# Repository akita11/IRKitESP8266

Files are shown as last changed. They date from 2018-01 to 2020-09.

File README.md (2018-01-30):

IRKitESP8266
=====

IRKit Clone on ESP8266

## これは何

Toshiyuki Kawashima氏の[ESP8266IRKit](https://github.com/toskaw/ESP8266IRKit) をベースに、以下の2点の追加・改変を行ったものです。
* ボタンを追加、長押しで初期化(電源ON時にも有効)
* 動作状態をLED(WS2812B)で表示

## 基板データ

IRKitESP8266.{brd,sch}がEagleデータです。適当な方法で製造してください。

※LED電流制限抵抗としてR4とR11の2つがありますが、どちらか一方のみの実装でよいです。流れる電流からして、R11のほうがオススメです（13Ωと書いてありますが、10Ω前後のものでよいはず）。ただこのあたりは要調整で、SwitchScienceのESP-IRではもっと小さな抵抗を使っているようです。10Ωか4.7Ωの0603サイズ（インチ：ミリだと1608）を、R4とR11の両方に実装するくらいでいいかもです（試していないのでLED破損の恐れがありますので要注意）。

なおオリジナルIRKitの基板と、穴の位置やコネクタの位置を基本的にあわせてあるので、オリジナルの筐体を流用できます。ただしオリジナルの赤外線LEDは2個なので、その筐体に合わせる場合は、LEDはD3とD4のみとりつけ、電流制限抵抗R4/R11もそれにあわせて調節してください。なおステータス表示LEDは基板上に上向きに実装されるため、オリジナル筐体にはあいません。またタクトスイッチの位置・種類がオリジナルと異なります。ご了承ください。

※初期化用タクトスイッチをオリジナル筐体にあうように追加し、プログラム用ショートピンの位置を少しずらし、ESP8266のアンテナ周囲のベタGNDを設計ガイドラインにあわせてあけたv1.1を追加しました(C5の位置が変更になっています)。ただし実際の製造・検証はしてませんのでご了承ください。

## ソースコード

上記のToshiyuki Kawashima氏の「作り方（ソースからコンパイルする方法）」の通りに進めます。

## 使い方

基本的に純正IRKitと同じです。スマホのIRKitアプリで初期設定を行ってください。初期パスワードは"0000000000"です。

## 参考にしたもの

* [minlRum](https://github.com/9SQ/minIRum)

* [IRKit](http://getirkit.com/)

* [ESP8266IRKit](https://github.com/toskaw/ESP8266IRKit)

## 直近のToDo
* LED点滅を、一応実装した（1秒周期）が、IR受信時の点滅を本家にあわせたい。
* 基板の外形・部品位置を、オリジナル筐体にあうように、以下の修正をしたい。
** uUSBコネクタの位置
** 初期化タクトスイッチ
** 角を丸める

## Author

Junichi Akita (@akita11, akita@ifdl.jp)

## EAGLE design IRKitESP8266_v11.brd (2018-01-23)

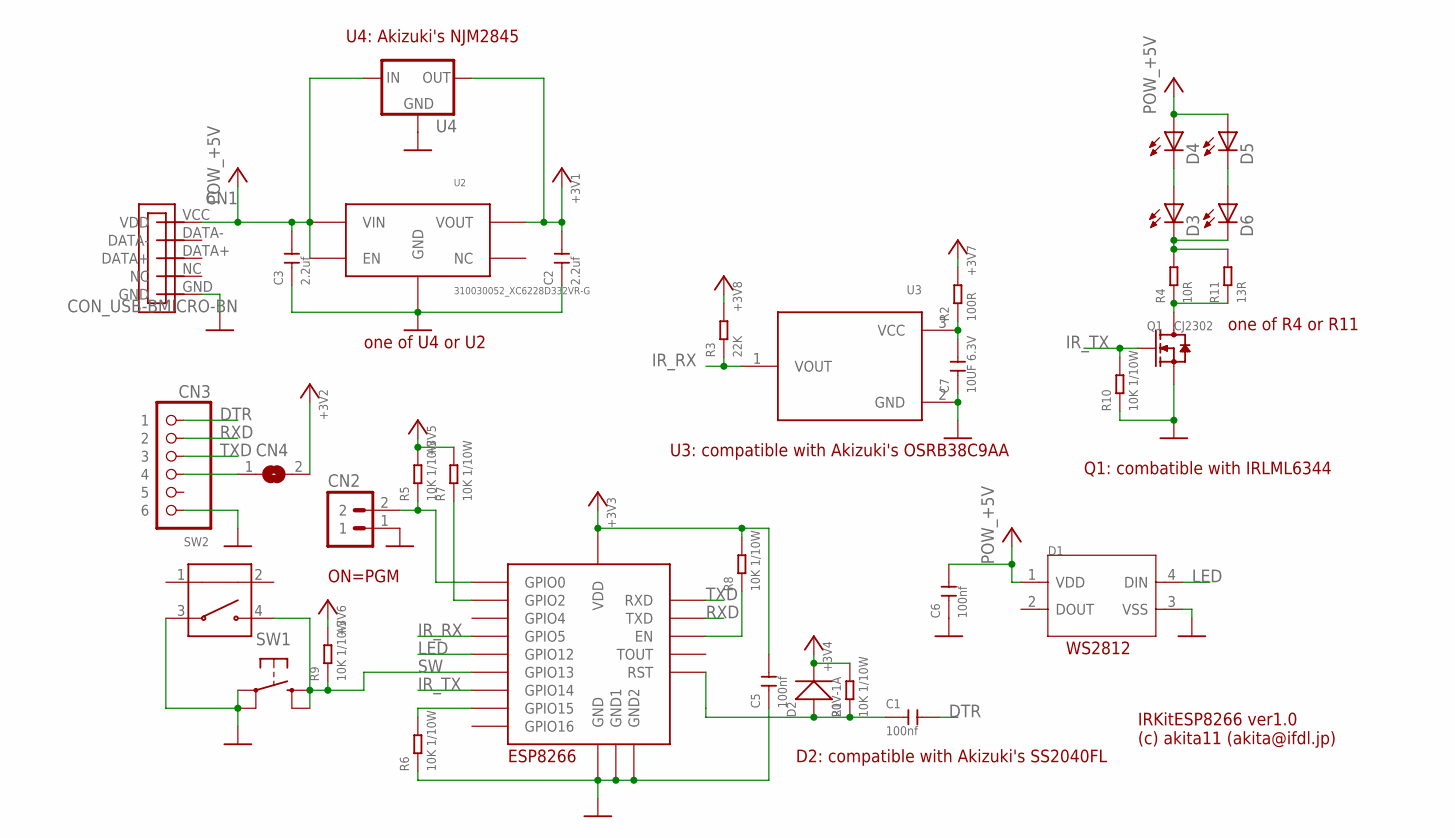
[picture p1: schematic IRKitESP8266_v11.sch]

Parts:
C1, C5, C6: 100nf; C0603
C2, C3: 2.2uf; C0603
C7: 10UF 6.3V; C0603
CN1: CON_USB-BMICRO-BN; MICRO-USB_B_NARROW
CN2: CON_PINHD-1X2PTH; SPARKFUN_1X02
CN3: CON_PINHD-1X6; 1X06
CN4: JUMPER_SJ
D1: SMD-RGB-LED-4P'WS2812B'; LED4-SMD-5050
D2: 20V-1A; SOD-123
D3, D4, D5, D6: LED5MM; SPARKFUN_LED5MM
Q1: CJ2302; SOT-23
R1, R5, R6, R7, R8, R9, R10: 10K 1/10W; R0603
R2: 100R; R0603
R3: 22K; R0603
R4: 10R; R0603
R11: 13R; R1206
SW1: SW_TACTTH; SW_B3F-10XX
SW2: TS-1188E
U1: MOD_ESP8266WROOM02
U2: 310030052_XC6228D332VR-G; SOT25J
U3: TSOP382
U4: REG_78XXTO252-3; TO-252-3

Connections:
+3V3: C2.2, C5.2, CN4.2, D2.-, R1.2, R2.2, R3.2, R5.2, R7.2, R8.2, R9.2, U1.P$1 (VDD), U2.P$5 (VOUT), U4.P$3 (OUT)
+5V: C3.2, C6.2, CN1.VCC (VDD), D1.1 (VDD), D4.A, D5.A, U2.P$1 (VIN), U2.P$3 (EN), U4.P$1 (IN)
DTR: C1.2, CN3.1
GND: C2.1, C3.1, C5.1, C6.1, C7.1, CN1.GND, CN2.1, CN3.6, D1.3 (VSS), Q1.2 (S), R6.1, R10.1, SW1.3, SW1.4 (P1), SW2.3, U1.P$9 (GND), U1.P$13 (GND1), U1.P$18 (GND2), U2.P$2 (GND), U3.2 (GND), U4.P$2 (GND)
IR_RX: R3.1, U1.P$14 (GPIO5), U3.1 (VOUT)
IR_TX: Q1.1 (G), R10.2, U1.P$3 (GPIO14)
LED: D1.4 (DIN), U1.P$4 (GPIO12)
unnamed: C1.1, D2.+, R1.1, U1.P$15 (RST)
unnamed: R6.2, U1.P$6 (GPIO15)
unnamed: CN2.2, R5.1, U1.P$8 (GPIO0)
unnamed: R7.1, U1.P$7 (GPIO2)
unnamed: CN3.4, CN4.1
unnamed: R8.1, U1.P$2 (EN)
unnamed: C7.2, R2.1, U3.3 (VCC)
unnamed: Q1.3 (D), R4.1, R11.1
unnamed: D3.K (C), D6.K (C), R4.2, R11.2
unnamed: D3.A, D4.K (C)
unnamed: D5.K (C), D6.A
RXD: CN3.2, U1.P$12 (TXD)
SW: R9.1, SW1.1 (S), SW1.2 (S1), SW2.4, U1.P$5 (GPIO13)
TXD: CN3.3, U1.P$11 (RXD)

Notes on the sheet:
U3: compatible with Akizuki's OSRB38C9AA
D2: compatible with Akizuki's SS2040FL
ON=PGM
WS2812
ESP8266
Q1: combatible with IRLML6344
IRKitESP8266 ver1.0 (c) akita11 (akita@ifdl.jp)
U4: Akizuki's NJM2845
one of U4 or U2
one of R4 or R11

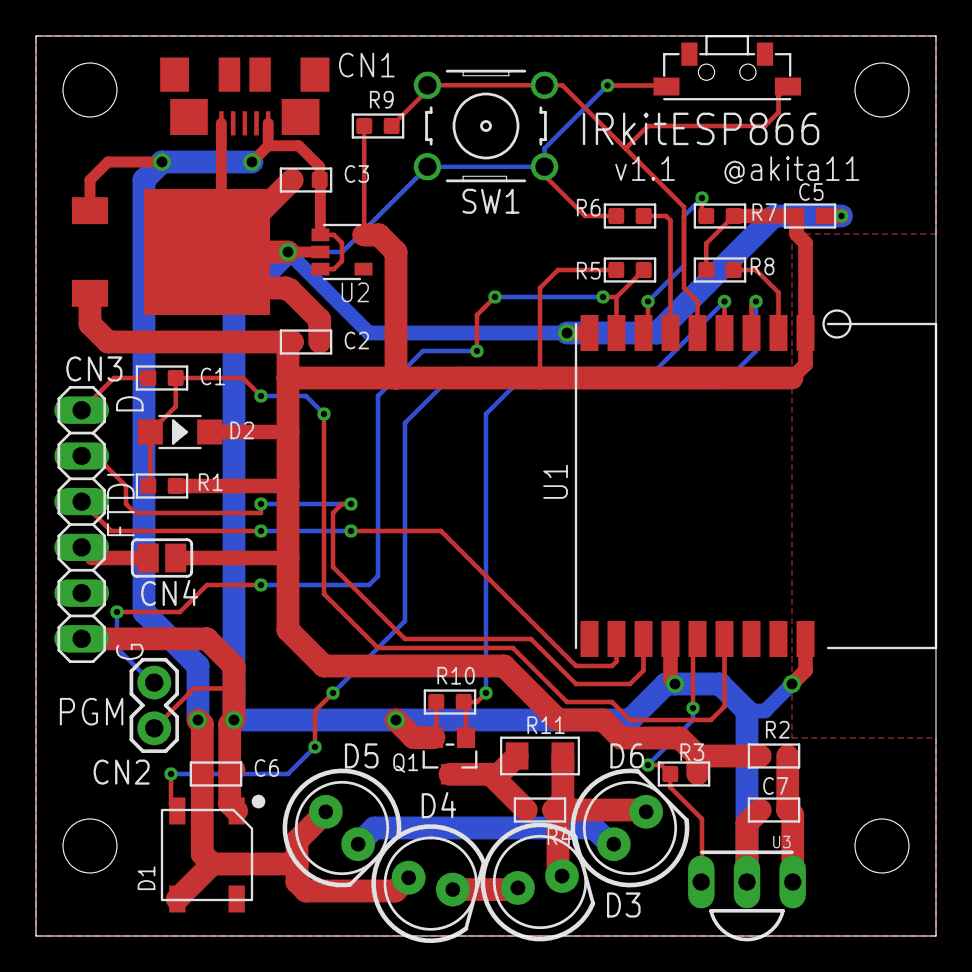
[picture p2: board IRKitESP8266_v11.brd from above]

Board: 2 copper layers, 50.0 x 50.0 mm, 34 parts (0 on the bottom side), 21 nets.

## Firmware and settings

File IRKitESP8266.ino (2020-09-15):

/*
 Copyright (C) 2018 Junichi Akita (@akita11, akita@ifdl.jp)

 This program is based on Toshiyuki Kawashima's ESP8266IRKit
 https://github.com/toskaw/ESP8266IRKit

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
 You should have received a copy of the GNU General Public License
 along with this program.  If not, see <http://www.gnu.org/licenses/>.
*/

/*
 Copyright (C) 2017 Toshiyuki Kawashima
  
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
 You should have received a copy of the GNU General Public License
 along with this program.  If not, see <http://www.gnu.org/licenses/>.
*/
#include "AsyncClient.h"
#include "IrPacker.h"
#include <EEPROM.h>

#include <IRrecv.h>
#include <IRremoteESP8266.h>
#include <IRsend.h>
#include <IRtimer.h>
#include <IRutils.h>
#include <ir_Argo.h>
#include <ir_Daikin.h>
#include <ir_Fujitsu.h>
#include <ir_Kelvinator.h>
#include <ir_LG.h>
#include <ir_Mitsubishi.h>
#include <ir_Trotec.h>
#include <Adafruit_NeoPixel.h> // for IRkitESP8266 by akita11

#include <ESP8266WiFi.h>
#include <ESP8266WebServer.h>
#include <ESP8266mDNS.h>
#include <aJSON.h>
#include <base64.h>

#include <Ticker.h>

#define VERSION "3.2.0.3.esp8266"
#define HOST "http://deviceapi.getirkit.com"
#define RECV_TIMEOUT 100U
#define RECV_BUFF 1024
#define JSON_BUFF 4096
#define SHARED_BUFFER_SIZE 512

const int send_pin = 14;
const int recv_pin = 5;
const int led_pin = 12; // for IRkitESP8266 by akita11
const int sw_pin = 13;  // for IRkitESP8266 by akita11
const char WAIT_RESPONSE = 'a';
const char DONE = 'b';
static uint32_t newest_message_id = 0;
char localName[10] = "IRKit";
uint16 irLen = 0;

// for IRkitESP8266 by akita11
Adafruit_NeoPixel pix = Adafruit_NeoPixel(1, led_pin, NEO_GRB + NEO_KHZ800);
Ticker ticker;
uint8_t LEDr = 0, LEDg = 0, LEDb = 0, fBlink = 0;
#define BLINK_INTERVAL 500 // [ms], 1000->500

// for IRkitESP8266 by akita11
// IRKit LED
//  赤       Wi-Fiに接続していない
//  赤点滅   セットアップ待ち
//  緑点滅   Wi-Fiに接続中
//  水色点滅 Wi-Fi接続成功！HTTPサーバなどセットアップ中
//  青	     正常
//  青点滅   赤外線信号を送受信中
//  ※現在は、青点滅は受信に同期せず、他と同じ一定周期点滅にしている(akita11)

void set_led(int r, int g, int b, uint8_t f_blink){
  LEDr = r; LEDg = g; LEDb = b;
  fBlink = f_blink;
  pix.setPixelColor(0, pix.Color(LEDr, LEDg, LEDb));
  pix.show();
}

void LEDblink()
{
  if (fBlink != 0){
    if (fBlink == 1){
      pix.setPixelColor(0, pix.Color(LEDr, LEDg, LEDb));
      fBlink = 2;
    }
    else if (fBlink == 2){
      pix.setPixelColor(0, pix.Color(0, 0, 0));
      fBlink = 1;
    }
    pix.show();
  }
}

const int LED_FULL = 50; // 100 -> 50

int polling = 0;
struct CONFIG {
  char init;
  char ssid[32];
  char pass[64];
  char devicekey[32];
};

CONFIG gSetting;

void factory_reset()
{
  Serial.println("factory initialize; erasing WiFi settings");
  int i;
  for (i =0; i < 5; i++){
    set_led(LED_FULL, LED_FULL, LED_FULL, 0); delay(500);
    set_led(0, 0, 0, 0); delay(500);
  }
  gSetting.init = 0;
  strcpy(gSetting.ssid, "");
  strcpy(gSetting.pass, "");
  EEPROM.put<CONFIG>(0, gSetting);
  EEPROM.commit();
  EEPROM.end();
  ESP.reset();
}
int sw_press_time = 0;  // for IRkitESP8266 by akita11
const int sw_long_press_time = 500;  // [x10ms] for IRkitESP8266 by akita11

struct irpacker_t packer_state;
ESP8266WebServer webServer(80);
AsyncClient polling_client;
char sharedbuffer[ SHARED_BUFFER_SIZE ];

IRsend irsend(send_pin);
IRrecv irrecv(recv_pin, RECV_BUFF, RECV_TIMEOUT, true);

#define ERR_NOBODY -1
#define ERR_FORMAT -2
#define ERR_EMPTY -3
char json[JSON_BUFF];

int irsendMessage(String& req) {
  int ret = 0;
  if (req.length() == 0) return ERR_EMPTY;
  irrecv.disableIRIn();
  
  req.toCharArray(json, JSON_BUFF);
  Serial.println(json);
  aJsonObject* root = aJson.parse(json);
  if (root != NULL) {
    aJsonObject* freq = aJson.getObjectItem(root, "freq");
    aJsonObject* data = aJson.getObjectItem(root, "data");
    aJsonObject* id = aJson.getObjectItem(root, "id");
    if (freq != NULL && data != NULL) {
      aJsonObject* node = data->child;
      if (node != NULL) {
        uint16_t d_size = 0;
        while (node) {
          d_size += 1;
          node = node->next;       
        }
        uint16_t rawData[d_size];
        int i = 0;
        node = data->child;
        while (node)  {
          rawData[i] = node->valueint;
          i += 1;
          node = node->next;
        }
        if (freq->type == aJson_Int) {
          irsend.sendRaw(rawData, d_size, (uint16_t)freq->valueint);
        }
        else if (freq->type == aJson_Float) {
          irsend.sendRaw(rawData, d_size, (uint16_t)freq->valuefloat);          
        }
        else {
          // 本当はエラーだけど38決め打ち
          irsend.sendRaw(rawData, d_size, 38);
        }
        Serial.println("irsend");
        if (id == NULL) {
          // polling suspend
          polling = 1;
        }
      }
      else {
        ret = ERR_FORMAT;
      }
      
      if (id != NULL) {
        newest_message_id = id->valueint;
       }
    } else {
      ret =  ERR_FORMAT;
    }
    aJson.deleteItem(root);
  } else {
    ret = ERR_NOBODY;
  }
  irrecv.enableIRIn();
  return ret;  
}

void sendheader() {
  webServer.sendHeader("Access-Control-Allow-Origin", "*");
  String server = "IRKit/";
  server += VERSION;
  webServer.sendHeader("Server", server);
}

void handleMessages() {
  Serial.println(webServer.uri().c_str());
  sendheader();
  if (!webServer.hasHeader("X-Requested-With")) {
    webServer.send(400, "text/plain", "Invalid Request");
    return;
  }
  if (webServer.method() == HTTP_POST) {
    Serial.println("post");
    String req = webServer.arg(0);
    if (req != NULL) {
      int err = irsendMessage(req);
      if (err == 0) {
        webServer.send(200, "text/plain", "ok");
      }
      else if (err == ERR_FORMAT) {
        webServer.send(400, "text/plain", "Invalid JSON format");
      }
      else {
        webServer.send(400, "text/plain", "No Data");
      }
    }
    else {
      Serial.println("err");
      webServer.send(400, "text/plain", "No Data");      
    }
  }
  else if (webServer.method() == HTTP_GET) {
    String s = "{\"format\":\"raw\",\"freq\":38,\"data\":[";
    int length = irLen;
    irpacker_unpack_start(&packer_state);
    for (int i= 0; i < length - 1; i += 1) {
      s += irpacker_unpack(&packer_state);
      s += ",";
    }
    s += irpacker_unpack(&packer_state);
    s += "]}";
    webServer.send(200, "text/plain", s);
  }
}

void handleKeys() {
  // devicekey=[0-9A-F]{32}
  if (!webServer.hasHeader("X-Requested-With")) {
    webServer.send(400, "text/plain", "Invalid Request");
    return;
  }
  char body[64];
  char url[64];
  sprintf(body, "devicekey=%s", gSetting.devicekey);
  HTTPClient client;
  sprintf(url, "%s%s", HOST, "/k");
  client.begin(url);
  client.setUserAgent("IRKit");
  client.addHeader("Content-Type", "application/x-www-form-urlencoded");
  int code = client.POST((uint8_t*)body, strlen(body));
  if (code == HTTP_CODE_OK) {
    sendheader();
    webServer.send(200, "text/plain", client.getString()); 
  }
  client.end();
}
void handleIndex() {
  String s = "<html lang=\"en\"><head><meta charset=\"utf-8\"/><meta name=\"viewport\" content=\"width=device-width, initial-scale=1\"><title>minIRum</title><link rel=\"stylesheet\" href=\"https://cdnjs.cloudflare.com/ajax/libs/twitter-bootstrap/3.3.7/css/bootstrap.min.css\" /><script src=\"https://cdnjs.cloudflare.com/ajax/libs/jquery/3.2.1/jquery.min.js\"></script><script src=\"https://cdnjs.cloudflare.com/ajax/libs/twitter-bootstrap/3.3.7/js/bootstrap.min.js\"></script></head><body><div class=\"container\"><div class=\"row\"><div class=\"col-md-12\"><h1>minIRum console <small>";
  s += localName;
  s += ".local</small></h1><p>IP address: ";
  s += String(WiFi.localIP()[0]) + "." + String(WiFi.localIP()[1]) + "." + String(WiFi.localIP()[2]) + "." + String(WiFi.localIP()[3]);
  s += "</p><hr><div class=\"form-group\"><textarea class=\"form-control\" id=\"message\" rows=\"10\"></textarea></div><button class=\"btn btn-primary\" id=\"get\">GET</button> <button class=\"btn btn-success\" id=\"post\">POST</button> <button class=\"btn btn-info\" id=\"ifttt\">IFTTT PARAM</button></div>";
  s += "<script>var xhr = new XMLHttpRequest();var textarea = document.getElementById(\"message\");document.getElementById(\"get\").addEventListener(\"click\", function () {xhr.open('GET', '/messages', true);xhr.setRequestHeader('X-Requested-With', 'curl');xhr.onreadystatechange = function() {if(xhr.readyState == 4) {textarea.value =xhr.responseText;}};xhr.send(null);});";
  s += "document.getElementById(\"post\").addEventListener(\"click\", function () {data = textarea.value;xhr.open('POST', '/messages', true);xhr.onreadystatechange = function() {if(xhr.readyState == 4) {alert(xhr.responseText);}};xhr.setRequestHeader('Content-Type', 'application/json');xhr.setRequestHeader('X-Requested-With', 'curl');xhr.send(data);});";
  s += "document.getElementById(\"ifttt\").addEventListener(\"click\", function () {xhr.open('POST', '/keys', true);xhr.onreadystatechange = function() {if(xhr.readyState == 4) {data = JSON.parse(xhr.responseText);param = 'clienttoken=' + data.clienttoken; var xhr2 = new XMLHttpRequest(); xhr2.open('POST', 'https://api.getirkit.com/1/keys', true);xhr2.onreadystatechange = function() {if(xhr2.readyState == 4) {data=JSON.parse(xhr2.responseText);message = textarea.value;param = 'clientkey=' + data.clientkey + '&deviceid=' + data.deviceid +'&message=' + message; textarea.value = param;}};xhr2.setRequestHeader('Content-Type', 'application/x-www-form-urlencoded');xhr2.send(param);}};xhr.setRequestHeader('Content-Type', 'application/json');xhr.setRequestHeader('X-Requested-With', 'curl');xhr.send('');});";
  s += "</script></body></html>";
  sendheader();
  webServer.send(200, "text/html", s);
}

void handleNotFound() {
  Serial.println(webServer.uri().c_str());
  Serial.println("404");
  sendheader();
  webServer.send(404, "text/plain", "Not found.");
}

void handleReset() {
  sendheader();
  if (!webServer.hasHeader("X-Requested-With")) {
    webServer.send(400, "text/plain", "Invalid Request");
    return;
  }
  webServer.send(200, "text/plain", "Reboot.");
  webServer.close();
  gSetting.init = 0;
  Serial.println("reset");
  EEPROM.put<CONFIG>(0, gSetting);
  EEPROM.commit();
  EEPROM.end();

  // reset
  ESP.reset();
}

void decodeParam(String& param, char *buffer) {
  int length = param.length();
  char high = 0;
  char low = 0;
  for (int i = 0; length > i; i+=2) {
      high = param.charAt(i);
      if (high < 'A') {
        high = high - '0';
      }
      else {
        high = high - 'A' + 10;
      }
      high *= 16;
      low = param.charAt(i + 1);
      if (low < 'A') {
        low = low - '0';
      }
      else {
        low = low - 'A' + 10;
      }
      *buffer = (char)(high + low);
      buffer += 1;
  }
  *buffer = '\0';
}

void handleWifiPost() {
  if (!webServer.hasHeader("X-Requested-With")) {
    webServer.send(400, "text/plain", "Invalid Request");
    return;
  }

  String data = webServer.arg(0);
  Serial.println("wifi request");
  Serial.println(data.c_str());

  // decode ssid
  int index = data.indexOf('/');
  int end_index = data.indexOf('/', index + 1);
  String param = data.substring(index + 1, end_index);
  Serial.println(param.c_str());
  decodeParam(param, gSetting.ssid);
  Serial.println(gSetting.ssid);

  // decode password
  index = data.indexOf('/', end_index);
  end_index = data.indexOf('/', index + 1);
  param = data.substring(index + 1, end_index);
  Serial.println(param.c_str());
  decodeParam(param, gSetting.pass);
  Serial.println(gSetting.pass);

  // decode devicekey
  index = data.indexOf('/', end_index);
  end_index = data.indexOf('/', index + 1);
  param = data.substring(index + 1, end_index);
  strcpy(gSetting.devicekey, param.c_str());
  Serial.println(gSetting.devicekey);
  
  gSetting.init = WAIT_RESPONSE;
  EEPROM.put<CONFIG>(0, gSetting);
  EEPROM.commit();
  EEPROM.end();
  String html = "";
  html += "<h1>WiFi Settings</h1>";
  webServer.send(200, "text/html", html);
  webServer.close();
  // reset
  ESP.reset();
}

String dumpIRcode(decode_results *results) {
  String s = "";
  for (int i = 1;  i < results->rawlen;  i++) {
    s += results->rawbuf[i] * RAWTICK;
    if ( i < results->rawlen - 1 ) s += ",";
  }
  return s;
}

void APMode() {
    char* ssid;
    const char* password = "0000000000";

    ssid = localName;
    IPAddress local_IP(192,168,1,1);
    IPAddress subnet(255,255,255,0);
    WiFi.mode(WIFI_AP);
    WiFi.softAPConfig(local_IP, local_IP, subnet);
    WiFi.softAP(ssid, password);
    delay(1000);
    Serial.println("");
    Serial.println("softAP Start");  
    Serial.print("IP address: ");
    Serial.println(WiFi.softAPIP());
#if 0    
    if (MDNS.begin(localName, WiFi.softAPIP())) {
      MDNS.addService("irkit", "tcp", 80);
      Serial.println("MDNS responder started.");
      Serial.print("http://");
      Serial.print(localName);
      Serial.println(".local");
    }
#endif
    webServer.on("/wifi", HTTP_POST, handleWifiPost);
}

#if 0
void dump(decode_results *results) {
  // Dumps out the decode_results structure.
  // Call this after IRrecv::decode()
  uint16_t count = results->rawlen;
  if (results->decode_type == UNKNOWN) {
    Serial.print("Unknown encoding: ");
  } else if (results->decode_type == NEC) {
    Serial.print("Decoded NEC: ");
  } else if (results->decode_type == SONY) {
    Serial.print("Decoded SONY: ");
  } else if (results->decode_type == RC5) {
    Serial.print("Decoded RC5: ");
  } else if (results->decode_type == RC5X) {
    Serial.print("Decoded RC5X: ");
  } else if (results->decode_type == RC6) {
    Serial.print("Decoded RC6: ");
  } else if (results->decode_type == RCMM) {
    Serial.print("Decoded RCMM: ");
  } else if (results->decode_type == PANASONIC) {
    Serial.print("Decoded PANASONIC - Address: ");
    Serial.print(results->address, HEX);
    Serial.print(" Value: ");
  } else if (results->decode_type == LG) {
    Serial.print("Decoded LG: ");
  } else if (results->decode_type == JVC) {
    Serial.print("Decoded JVC: ");
  } else if (results->decode_type == AIWA_RC_T501) {
    Serial.print("Decoded AIWA RC T501: ");
  } else if (results->decode_type == WHYNTER) {
    Serial.print("Decoded Whynter: ");
  } else if (results->decode_type == NIKAI) {
    Serial.print("Decoded Nikai: ");
  }
  serialPrintUint64(results->value, 16);
  Serial.print(" (");
  Serial.print(results->bits, DEC);
  Serial.println(" bits)");
  Serial.print("Raw (");
  Serial.print(count, DEC);
  Serial.print("): {");

  for (uint16_t i = 1; i < count; i++) {
    if (i % 100 == 0)
      yield();  // Preemptive yield every 100th entry to feed the WDT.
    if (i & 1) {
      Serial.print(results->rawbuf[i] * RAWTICK, DEC);
    } else {
      Serial.print(", ");
      Serial.print((uint32_t) results->rawbuf[i] * RAWTICK, DEC);
    }
  }
  Serial.println("};");
}
#endif

void setup() {
  Serial.begin(115200);
  Serial.println();
  pinMode(sw_pin, INPUT); digitalWrite(sw_pin, HIGH); // for IRkitESP8266 by akita11
  pix.begin(); // for IRkitESP8266 by akita11
  set_led(LED_FULL, 0, 0, 0);

  EEPROM.begin(200);
  EEPROM.get<CONFIG>(0, gSetting);
  Serial.println("Confing:");
  Serial.println(gSetting.init);
  Serial.println(gSetting.ssid);
  Serial.println(gSetting.pass);
  Serial.println(gSetting.devicekey);

  // factory reset, if SW is pressed at boot
  if (digitalRead(sw_pin) == 0){
    set_led(LED_FULL, LED_FULL, LED_FULL, 0);
    while(digitalRead(sw_pin) == 0 && sw_press_time < sw_long_press_time){
      sw_press_time++; delay(10);
    }
    if (sw_press_time >= sw_long_press_time){
      // long press --> initialization (delete WiFi config)
      factory_reset();
    }
    else set_led(0, 0, 0, 0);
  }

  // ref: https://www.sglabs.jp/esp-wroom-02-ticker/
  ticker.attach_ms(BLINK_INTERVAL, LEDblink);

  byte mac[6];
  char buf[6];
  WiFi.macAddress(mac);
  sprintf(buf, "%02X%02X", mac[4], mac[5]);
  strcat(localName, buf);
  const char * headerkeys[] = {"X-Requested-With"};
  size_t headerkeyssize = sizeof(headerkeys)/sizeof(char*);
  webServer.collectHeaders(headerkeys, headerkeyssize );
  char* ssid;
  char* password;
  if (gSetting.init != DONE && gSetting.init != WAIT_RESPONSE) {
    // status: red blink // for IRkitESP8266 by akita11
    set_led(LED_FULL, 0, 0, 1);
    APMode();
  }
  else {
    // status: green blink // for IRkitESP8266 by akita11
    set_led(0, LED_FULL, 0, 1);
    ssid = gSetting.ssid;
    password = gSetting.pass;
    WiFi.mode(WIFI_STA);
    Serial.print("conecting to SSID:"); Serial.println(ssid);
    WiFi.begin(ssid, password);
    irsend.begin();
    irrecv.enableIRIn();
    uint8 retry = 1000;
    while (WiFi.status() != WL_CONNECTED && retry) {
      delay(200);
      Serial.print(".");
      retry -= 1;
    }
    if (retry == 0 && gSetting.init == WAIT_RESPONSE) {
      // wifi error 
      gSetting.init = 0;
      EEPROM.put<CONFIG>(0, gSetting);
      EEPROM.commit();
      EEPROM.end();
      ESP.reset();
    }
    else if (retry == 0 && gSetting.init == DONE) {
      // 繋がらないのでとりあえずAPモード（設定は消さない)
      APMode();
    }
    else {
      Serial.println("");
      Serial.print("Connected to ");
      Serial.println(ssid);
      Serial.print("IP address: ");
      Serial.println(WiFi.localIP());
      // status: cyan blink // for IRkitESP8266 by akita11
      set_led(0, LED_FULL, LED_FULL, 1);
      if (MDNS.begin(localName, WiFi.localIP())) {
        //MDNS.addService("http", "tcp", 80);
        MDNS.addService("irkit", "tcp", 80);
        Serial.println("MDNS responder started.");
        Serial.print("http://");
        Serial.print(localName);
        Serial.println(".local");
      }
      webServer.on("/messages", handleMessages);
      webServer.on("/keys", handleKeys);
      webServer.on("/reset", handleReset);
 #if 1
      webServer.on("/", handleIndex);
 #endif
    }
  }
  webServer.onNotFound(handleNotFound);  
  webServer.begin();
  Serial.println("Web server started.");
  // status: blue // for IRkitESP8266 by akita11
  set_led(0, 0, LED_FULL, 0);
}

void loop() {
  webServer.handleClient();

  // for IRkitESP8266 by akita11
  sw_press_time = 0;
  if (digitalRead(sw_pin) == 0){
    set_led(LED_FULL, LED_FULL, LED_FULL, 0);
    while(digitalRead(sw_pin) == 0 && sw_press_time < sw_long_press_time){
      sw_press_time++; delay(10);
    }
    if (sw_press_time >= sw_long_press_time){
      // long press --> initialization (delete WiFi config)
      factory_reset();
    }
    else set_led(0, 0, 0, 0);
  }

  static char url[256];
  if (gSetting.init == WAIT_RESPONSE) {
    // post_door
    #define POST_DOOR_BODY_LENGTH 128
    char body[POST_DOOR_BODY_LENGTH];
    sprintf(body, "devicekey=%s&hostname=%s", gSetting.devicekey, localName);
    HTTPClient client;
    sprintf(url, "%s%s", HOST, "/d");
    client.begin(url);
    Serial.println(url);
    Serial.println(body);
    client.setUserAgent("IRKit");
    client.addHeader("Content-Type", "application/x-www-form-urlencoded");
    int code = client.POST((uint8_t*)body, strlen(body));
    if (code == HTTP_CODE_OK) { 
      gSetting.init = DONE;
      Serial.println("success");
      EEPROM.put<CONFIG>(0, gSetting);
      EEPROM.commit();
      EEPROM.end();
    }
    else {
      char buffer[10];
      sprintf(buffer, "%i", code);
      Serial.println(buffer);
    }
    client.end();
  }
  else if (gSetting.init == DONE) {
    // get messages
    sprintf(url, "%s/m?devicekey=%s&newer_than=%d", HOST, gSetting.devicekey, newest_message_id);
    if (polling_client.connected()) {
      int status = polling_client.handleClientLoop();
      if (status) {
        if (status == HTTP_CODE_OK) {
          String req = polling_client.getString();
          if (polling == 0 && req.length()) {
            irsendMessage(req);
          }
          else {
            polling = 0;
            if (req && req.length()) {
              // id 更新
              req.toCharArray(json, JSON_BUFF);  
              aJsonObject* root = aJson.parse(json);
              if (root != NULL) {
                aJsonObject* id = aJson.getObjectItem(root, "id");
                if (id != NULL) {
                  ::newest_message_id = id->valueint;
                }
                aJson.deleteItem(root);
              }
            }
          }
        }
        polling_client.end();
      }
    }
    else {
      polling_client.begin(url);
      polling_client.setTimeout(50 * 1000);
      polling_client.setUserAgent("IRKit");
      if (polling_client.AsyncGET() < 0) {
        // 切断
        polling_client.end();
      }
    }

    decode_results  results;
    
    if (irrecv.decode(&results)) {
      // status: blue blink // for IRkitESP8266 by akita11
      //dump(&results);
      Serial.println(dumpIRcode(&results));
      irLen = results.rawlen - 1;
      // pack
      memset( (void*)sharedbuffer, 0, sizeof(uint8_t) * SHARED_BUFFER_SIZE );
      irpacker_init( &packer_state, (uint8_t*)sharedbuffer );
       for (int i = 1;  i < results.rawlen;  i++) {
        irpacker_pack(&packer_state, results.rawbuf[i] * RAWTICK);
       }
       irpacker_packend(&packer_state);
      // post
      String body;
//      body = base64::encode(sharedbuffer, irpacker_safelength(&packer_state));
      body = base64::encode((uint8_t *)sharedbuffer, irpacker_safelength(&packer_state));
      sprintf(url, "%s/p?devicekey=%s&freq=%d", HOST, gSetting.devicekey, 38);
      HTTPClient client;
      client.setTimeout(10000);
      client.begin(url);
      client.setUserAgent("IRKit");
      client.addHeader("Content-Type", "application/x-www-form-urlencoded");
      int code = client.POST(body);
      if (code == HTTP_CODE_OK) { 
        Serial.println("post success");
       }
      else {
        Serial.println("post error");
      }
      client.end();
      irrecv.resume();
    }
  

#if 0 
    long mem = ESP.getFreeHeap();
    Serial.print("freeMemory()=");
    Serial.println(mem);
#endif
  }
  else {
    ;
  }
}

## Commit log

2018-01-21 必要ファイル一式を追加
    [IRKitESP8266.brd, IRKitESP8266.sch]
2018-01-21 README.mdのプログラム名のtypoを修正
2018-01-22 README.mdのtypoを修正
2018-01-22 README.mdに、LED点滅の実装予定を追記
2018-01-22 README.mdに、抵抗の実装方法について追記
2018-01-22 typoの修正、LED電流制限抵抗に関して追記。
2018-01-22 筐体に関する記述を追加
2018-01-23 初期化用タクトスイッチ（本家と同じ位置）を追加sita
    [IRKitESP8266_v11.brd, IRKitESP8266_v11.sch]
2018-01-23 ESP8266のアンテナ周囲のベタGNDの変更
    設計ガイドに沿って、アンテナ周囲のベタGNDをあけ、それにともなってC5の位置を移動
    [IRKitESP8266_v11.brd]
2018-01-24 ステータスLED点滅の実装
2018-01-30 電源ON時の初期化処理を追加。LED点滅周期・輝度の変更。
    READMEに、オリジナル筐体にあわせるための基板修正案を追記
2018-01-31 ソースの更新忘れを更新
2020-09-15 サーバ問い合わせ間隔を本家IRkitにあわせて5秒ごとに
2020-09-15 サーバ問い合わせ間隔を5秒にするdelayを削除
    そこに入れると赤外線読み取りが止まってしまうため、いったん元に戻す。

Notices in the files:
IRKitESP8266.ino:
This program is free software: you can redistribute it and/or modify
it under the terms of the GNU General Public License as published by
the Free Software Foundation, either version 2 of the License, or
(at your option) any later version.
